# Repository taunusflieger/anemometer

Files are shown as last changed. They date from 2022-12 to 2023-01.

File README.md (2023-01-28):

# ESP32-S3 Espressif based 3D printed Anemometer


## About

This project will replace my broken anemometer (wind speed and wind direction sensor). The project is structured into two parts a.) a calibration solution which uses GPS to calibrate the sensor and b.) a production version which will be embedded into the 3D printed anemometer. The anemometer will be connect through Wifi with AWS to send (MQTT) measurements to the cloud where a web site is hosted. Given that the anemometer will be mounted on the roof of my house, it is important to be able to update the device without connecting a computer to it. Therefor OTA is implemented. The device can be updated by sending a MQTT message. The device downloads the requested firmware version from an AWS S3 bucket. All communication is secured using mutual TLS authentication. I'm also planning to power the device with a battery and a solar cell, that will require the implementation of a power management approach utilizing the low power modes of the used MCU.

## Scope

### Technical
- Reliable wifi connection, automatic reconnect (same for MQTT)
- MQTT transport of sensor data to AWS IoT core
- OTA update through HTTPS from AWS S3
- SNTP client to enable X.509 certificate validation and time stamping of measurement data
- NeoPixel for Wifi connection status indication
- IRQ routine to record anemometer rotation pulses (not decided if this will be ESP32-S3 and ULP)
- Local web server on the device for instant data
- All configuration data, specifically the AWS related configuration is stored in a separate partition in the NVM
- The application is written in Rust leveraging the ESP IDF framework
- The production and calibration use cases both use an ESP32-S3 MCU. The main reason not to use the ESP32-C3 is it's 4MB flash size limit which is too small to enable OTA functionality
- For production a [TinyS3 from UM](https://esp32s3.com/tinys3.html) is used as this is the smallest ESP32-S3 I've found

### Functional
- HTML page for providing current wind speed and direction
- Data feed to AWS where an external web interface is hosted
- The firmware supports multiple anemometer instances, as device specific information is stored outside of the fw image

### Functional for calibration use-case
- TFT to display current GPS and current wind speed
- Serial connection to a GPS receiver
- Recording of anemometer rotation speed and GPS data on a Micro SD card

## What is working
- Reliable wifi re-connect. When the wifi connection gets dropped, a re-connection process is started. When an IP address is received the HTTP Server is started again.
- HTTP Server
- OTA firmware download from AWS S3
- MQTT (sending data from the device, control the device OTA / reset) connection to AWS IoT core
- NVS for configuration storage
- Support for Adafruit Feather ESP32-S3 TFT display controller ST7789 (similar to ST7735). Implementation approach uses [mipidsi driver](https://github.com/almindor/mipidsi) 
- Output of GPS speed on TFT
- Logging of GPS NMEA sentences and anemometer rotation speed (rps) to SD card
- Rotation speed of anemometer processing and exposing through web interface (/windspeed)

## Todo List
- [x] Support for Adafruit [Ultimate GPS FeatherWing](https://learn.adafruit.com/adafruit-ultimate-gps-featherwing) to support the calibration process for the wind speed parameters. This is only required for the calibration use-case.
- [x] Support for Adafruit [Adalogger FeatherWing](https://learn.adafruit.com/adafruit-adalogger-featherwing) to log wind speed and GPS data. Interface through [Embedded SD/MMC](https://github.com/rust-embedded-community/embedded-sdmmc-rs). This is only required for the calibration use-case.
- [x] Evaluate pros and cons for using ESP32-S3 vs ESP32-C3 (power consumption, sleep, local web server, OTA needs to be considered)
- [x] ISR & event counting for windspeed sensor
- [x] Fully implement the feature approach to separate the calibration use case from production use case. The image for calibration is too large to allow OTA. Display, GPS and SD Card are not required for production. The solution has been split into a calibration and production solution.
- [x] Implement configuration settings for production in a seperate NVS partition
- [x] Add support for SNTP for production use case
- [ ] Modify existing AWS IoT interface to deal with wind only data (not the full weather dataset which is currently processed)
- [x] Implement MQTT for data ingress to AWS
- [ ] Implement sleep mode (which one ?)
- [ ] Calibration of the anemometer
- [ ] Implement new UI for the AWS lamda based weather station App

## Hardware Images

The board-setup used for the calibration use-case:

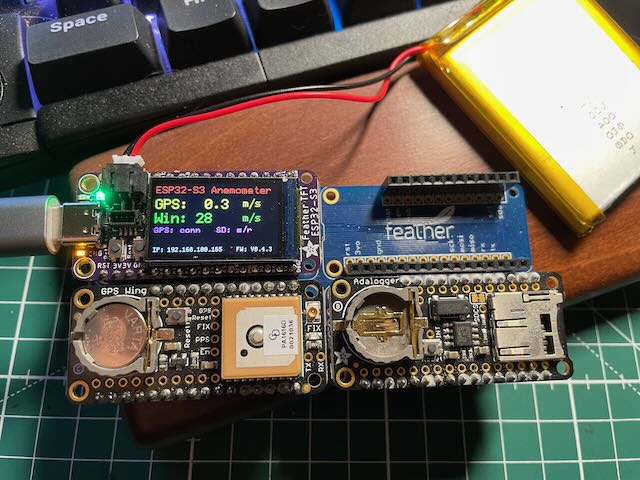
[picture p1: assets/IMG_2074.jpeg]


The 3D printed anemometer:

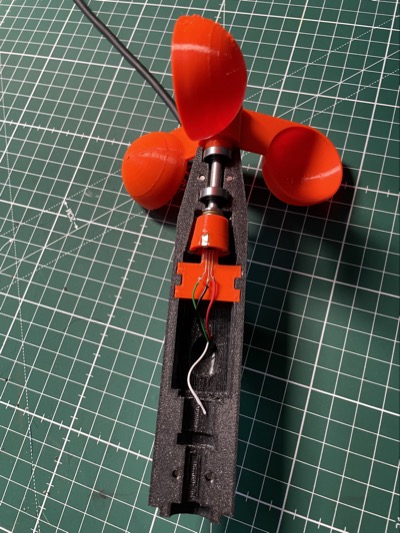
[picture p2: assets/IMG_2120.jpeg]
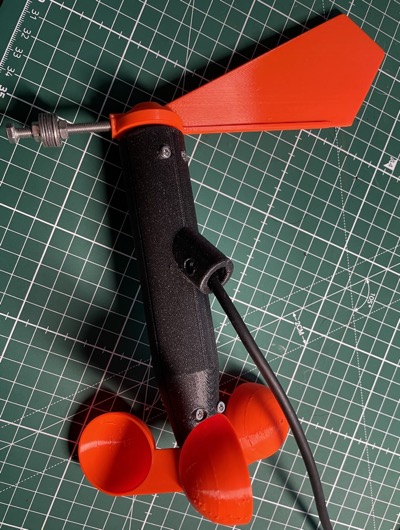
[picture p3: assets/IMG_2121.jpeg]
 

## Hardware BOM
- [SS41F](https://www.mouser.com/catalog/specsheets/hwsc-s-a0001295895-1.pdf). Hall- effect sensor to measure the rotation speed of the cups rotor

## License

Licensed under either of

- Apache License, Version 2.0 ([LICENSE-APACHE](LICENSE-APACHE) or
  http://www.apache.org/licenses/LICENSE-2.0)

- MIT license ([LICENSE-MIT](LICENSE-MIT) or http://opensource.org/licenses/MIT)

at your option.

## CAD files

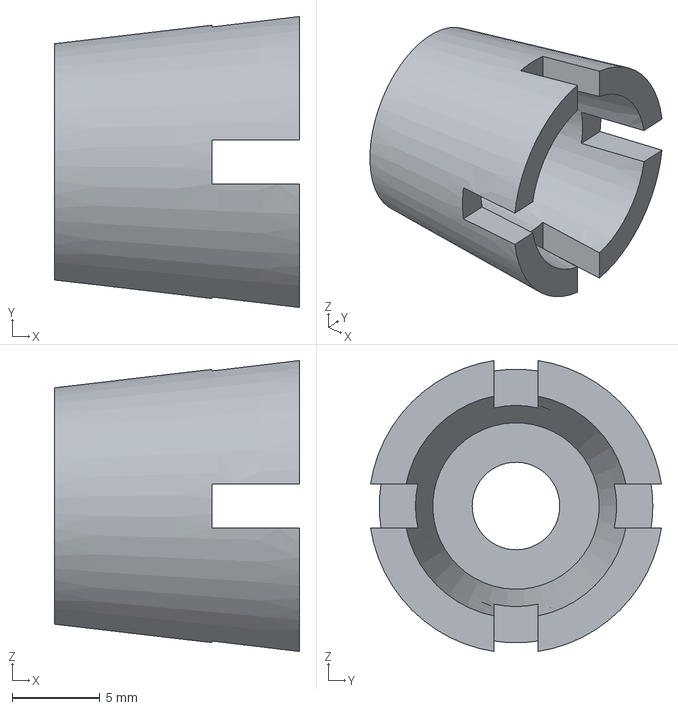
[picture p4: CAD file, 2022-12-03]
CAD/Magnetaufnahme.FCStd
14.0 x 16.6 x 16.6 mm

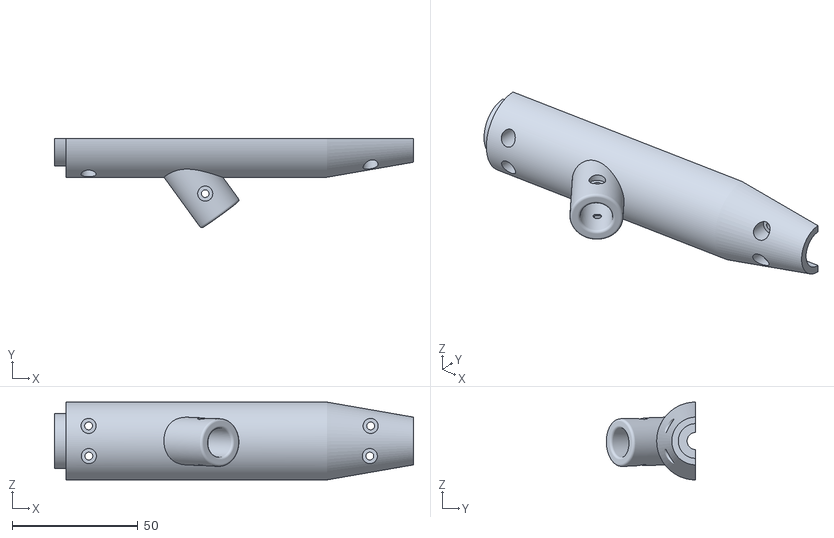
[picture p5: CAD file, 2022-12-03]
STL/housing_back.stl
142.9 x 35.5 x 31.0

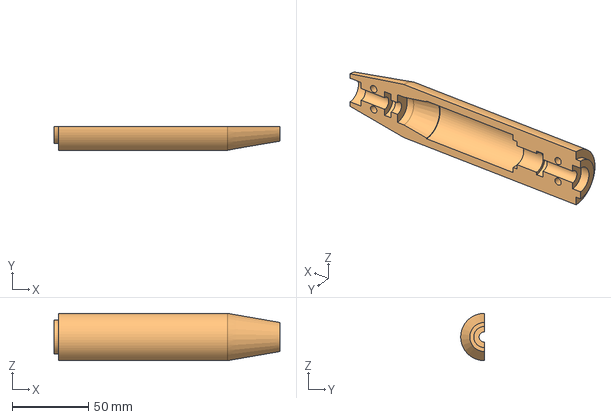
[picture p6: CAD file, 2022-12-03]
CAD/Housing_Bohrungen_front.FCStd
147.9 x 15.5 x 31.0 mm
Tube Corpus
Connect

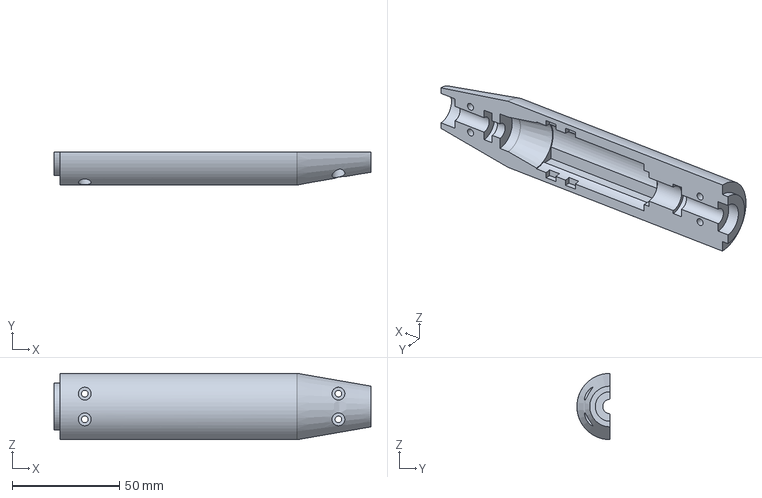
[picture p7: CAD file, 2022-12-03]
CAD/Housing_Bohrungen_back.FCStd
147.9 x 15.5 x 31.0 mm

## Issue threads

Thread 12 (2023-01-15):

minimal working OTA sample?

thomas725, 2023-01-15:
Hey there!

I'm currently trying to switch an ESP32 project of mine from Arduino to Rust because the Arduino software I've written get's sluggish over time and sometimes crashes, I suspect it has memory leaks.

Important feature I need is OTA, which seems is much more difficult with Rust than on Arduino, and your project is the first I've found that seems to have figured that one out. Sadly your project looks overwhelmingly big to my eyes, so I wanted to ask if you maybe could help me reach a minimal working OTA sample.

Thank you,
kind regards,
Thomas

taunusflieger, 2023-01-18:
Hi Thomas,the core OTA functionality is not much. Take a look at https://github.com/taunusflieger/anemometer/blob/master/anemometer-production/src/task/ota.rs
This where the fw download and the flashing happens.

taunusflieger, 2023-01-18:
.

Closed 2023-01-18.

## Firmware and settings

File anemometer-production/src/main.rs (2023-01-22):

/*
 * ESP32 Anemometer
 *
 * MIT license
 *
 * Copyright (c) 2021-2023 Michael Zill
 *
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
 * Apache license, Version 2.0
 *
 * Copyright (c) 2021-2023 Michael Zill
 *
 * Licensed under the Apache License, Version 2.0 (the "License");
 * you may not use this file except in compliance with the License.
 * You may obtain a copy of the License at
 *
 *     http://www.apache.org/licenses/LICENSE-2.0
 *
 * Unless required by applicable law or agreed to in writing, software
 * distributed under the License is distributed on an "AS IS" BASIS,
 * WITHOUT WARRANTIES OR CONDITIONS OF ANY KIND, either express or implied.
 * See the License for the specific language governing permissions and
 * limitations under the License.
 */
#![allow(incomplete_features)]
#![feature(generic_const_exprs)]
use crate::configuration::AwsIoTSettings;
use crate::global_settings::*;
use crate::services::*;
use crate::state::*;
use crate::task::{httpd, mqtt, ota::*, publisher};
use crate::utils::nvs_ext::*;
use crate::utils::{datetime, errors::*};
use channel_bridge::{asynch::pubsub, asynch::*};
use configuration::AwsIoTCertificates;
use edge_executor::*;
use edge_executor::{Local, Task};
use embedded_svc::utils::asyncify::Asyncify;
use embedded_svc::wifi::Wifi as WifiTrait;
use esp_idf_hal::reset::WakeupReason;
use esp_idf_hal::task::thread::ThreadSpawnConfiguration;
use esp_idf_hal::{cpu::*, task::executor::EspExecutor};
use esp_idf_svc::eventloop::EspSystemEventLoop;
use esp_idf_svc::netif::IpEvent;
use esp_idf_svc::nvs::EspDefaultNvsPartition;
use esp_idf_svc::nvs::*;
use esp_idf_svc::wifi::WifiEvent;
// If using the `binstart` feature of `esp-idf-sys`, always keep this module imported
use esp_idf_sys as _;
use esp_idf_sys::esp_ota_mark_app_valid_cancel_rollback;
use esp_idf_sys::{self as sys, esp, esp_wifi_set_ps, wifi_ps_type_t_WIFI_PS_MIN_MODEM};
use log::*;
use once_cell::sync::Lazy;
use std::sync::Mutex;

mod configuration;
mod data_processing;
mod global_settings;
mod mqtt_msg;
mod peripherals;
mod services;
mod state;
mod task;
mod utils;

//sys::esp_app_desc!();

static AWSCERTIFICATES: static_cell::StaticCell<AwsIoTCertificates> =
    static_cell::StaticCell::new();

pub static AWSCONFIG: Lazy<Mutex<AwsIoTSettings>> = Lazy::new(|| {
    Mutex::new(match AwsIoTSettings::new("conf") {
        Ok(settings) => settings,
        Err(err) => {
            error!("Failed to load AWS configuration: {err}");
            panic!();
        }
    })
});

fn main() -> core::result::Result<(), InitError> {
    esp_idf_hal::task::critical_section::link();
    esp_idf_svc::timer::embassy_time::driver::link();
    esp_idf_svc::timer::embassy_time::queue::link();

    esp_idf_svc::log::EspLogger::initialize_default();

    info!("ESP32-Anemometer");
    match core() {
        Core::Core0 => info!("running on core 0"),
        Core::Core1 => info!("running on core 1"),
    }
    let wakeup_reason = WakeupReason::get();
    info!("Wakeup reason: {:?}", wakeup_reason);

    let pm_config = esp_idf_sys::esp_pm_config_esp32s3_t {
        max_freq_mhz: MAX_CPU_FREQ,
        min_freq_mhz: MIN_CPU_FREQ,
        light_sleep_enable: LIGHT_SLEEP_MODE_ENABLED,
    };

    if let Err(err) =
        esp!(unsafe { esp_idf_sys::esp_pm_configure(&pm_config as *const _ as *const _) })
    {
        panic!("failed to set esp_pm_configure {err}");
    }

    let peripherals = peripherals::SystemPeripherals::take();
    let anemometer_peripherals = peripherals.pulse_counter;
    let nvs_default_partition = EspDefaultNvsPartition::take()?;
    let sysloop = EspSystemEventLoop::take()?;

    // Initialize data capture from anemometer
    let mut anemometer = anemometer::AnemometerDriver::new(anemometer_peripherals.pulse).unwrap();

    let _anemometer_timer = anemometer.set_measurement_timer().unwrap();

    let aws_iot_certificates: &'static AwsIoTCertificates =
        AWSCERTIFICATES.init(match AwsIoTCertificates::new("conf") {
            Ok(settings) => settings,
            Err(err) => {
                error!("Failed to load AWS configuration: {err}");
                panic!();
            }
        });

    let (wifi, wifi_notif) = wifi(
        peripherals.modem,
        sysloop.clone(),
        Some(nvs_default_partition),
    )?;

    esp!(unsafe { esp_wifi_set_ps(wifi_ps_type_t_WIFI_PS_MIN_MODEM) })?;

    let _sntp = utils::datetime::initialize();

    ThreadSpawnConfiguration {
        name: Some(b"high-prio-executor\0"),
        priority: TASK_HIGH_PRIORITY,
        ..Default::default()
    }
    .set()?;

    let _high_prio_execution = schedule::<8, _>(40000, move || {
        let executor = EspExecutor::new();
        let mut tasks = heapless::Vec::new();

        executor.spawn_local_collect(ota_task(aws_iot_certificates), &mut tasks)?;
        executor.spawn_local_collect(process_wifi_state_change(wifi, wifi_notif), &mut tasks)?;

        executor.spawn_local_collect(
            process_netif_state_change(netif_notifier(sysloop.clone()).unwrap()),
            &mut tasks,
        )?;

        Ok((executor, tasks))
    });

    ThreadSpawnConfiguration {
        name: Some(b"mid-prio-executor\0"),
        priority: TASK_MID_PRIORITY,
        ..Default::default()
    }
    .set()?;

    std::thread::sleep(core::time::Duration::from_millis(8000));

    let _mid_prio_execution = schedule::<8, _>(8000, move || {
        let executor = EspExecutor::new();
        let mut tasks = heapless::Vec::new();
        let (mqtt_client, mqtt_conn) = services::mqtt(aws_iot_certificates).unwrap();

        executor.spawn_local_collect(
            mqtt::send_task::<MQTT_MAX_TOPIC_LEN>(mqtt_client),
            &mut tasks,
        )?;
        executor.spawn_local_collect(mqtt::receive_task(mqtt_conn), &mut tasks)?;
        Ok((executor, tasks))
    });

    ThreadSpawnConfiguration {
        name: Some(b"low-prio-executor\0"),
        priority: TASK_LOW_PRIORITY,
        ..Default::default()
    }
    .set()?;

    let low_prio_execution = schedule::<8, _>(32000, move || {
        let executor = EspExecutor::new();
        let mut tasks = heapless::Vec::new();
        executor.spawn_local_collect(publisher::wind_speed_task(), &mut tasks)?;
        //executor.spawn_local_collect(httpd::http_server_task(), &mut tasks)?;

        Ok((executor, tasks))
    });

    if let Ok(datetime) = datetime::get_datetime() {
        let format =
            time::format_description::parse("[day].[month].[year] [hour]:[minute]:[second]")
                .expect("Invalid format.");

        let time = datetime.format(&format).expect("Could not format time.");
        info!("System start time: {time}");
    }

    low_prio_execution.join().unwrap();

    unreachable!();
}

pub fn schedule<'a, const C: usize, M>(
    stack_size: usize,
    spawner: impl FnOnce() -> core::result::Result<
            (Executor<'a, C, M, Local>, heapless::Vec<Task<()>, C>),
            SpawnError,
        > + Send
        + 'static,
) -> std::thread::JoinHandle<()>
where
    M: Monitor + Wait + Default,
{
    std::thread::Builder::new()
        .stack_size(stack_size)
        .spawn(move || {
            let (executor, tasks) = spawner().unwrap();

            executor.run_tasks(|| true, tasks);
        })
        .unwrap()
}

#[inline(always)]
pub fn netif_notifier(
    mut sysloop: EspSystemEventLoop,
) -> core::result::Result<impl Receiver<Data = IpEvent>, InitError> {
    Ok(pubsub::SvcReceiver::new(sysloop.as_async().subscribe()?))
}

pub async fn process_wifi_state_change(
    mut wifi: impl WifiTrait,
    mut state_changed_source: impl Receiver<Data = WifiEvent>,
) {
    loop {
        let event = state_changed_source.recv().await.unwrap();

        match event {
            WifiEvent::StaConnected => {}
            WifiEvent::StaDisconnected => {
                let mut publisher = NETWORK_EVENT_CHANNEL.publisher().unwrap();
                let _ = publisher.send(NetworkStateChange::WifiDisconnected).await;
                let _ = wifi.connect();
            }
            _ => {}
        }
    }
}

pub async fn process_netif_state_change(mut state_changed_source: impl Receiver<Data = IpEvent>) {
    loop {
        if let IpEvent::DhcpIpAssigned(assignment) = state_changed_source.recv().await.unwrap() {
            info!("IpEvent: DhcpIpAssigned: {:?}", assignment.ip_settings.ip);

            // if an IP address has been succesfully assiggned we consider
            // the application working, no rollback required.
            unsafe { esp_ota_mark_app_valid_cancel_rollback() };

            let mut publisher = NETWORK_EVENT_CHANNEL.publisher().unwrap();
            let _ = publisher
                .send(NetworkStateChange::IpAddressAssigned {
                    ip: assignment.ip_settings.ip,
                })
                .await;
        }
    }
}

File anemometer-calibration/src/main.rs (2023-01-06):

/*
 * ESP32 Anemometer
 *
 * MIT license
 *
 * Copyright (c) 2021-2023 Michael Zill
 *
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
 * Apache license, Version 2.0
 *
 * Copyright (c) 2021-2023 Michael Zill
 *
 * Licensed under the Apache License, Version 2.0 (the "License");
 * you may not use this file except in compliance with the License.
 * You may obtain a copy of the License at
 *
 *     http://www.apache.org/licenses/LICENSE-2.0
 *
 * Unless required by applicable law or agreed to in writing, software
 * distributed under the License is distributed on an "AS IS" BASIS,
 * WITHOUT WARRANTIES OR CONDITIONS OF ANY KIND, either express or implied.
 * See the License for the specific language governing permissions and
 * limitations under the License.
 */
use crate::anemometer::{AnemometerDriver, GLOBAL_ANEMOMETER_DATA};
use crate::gps_mtk3339::gps;
use crate::gps_mtk3339::gps::Mtk3339;
use crate::screen::anemometer_screen::LayoutManager;
use crate::web_server::url_handler;
use chrono::NaiveTime;
use core::mem;
use embedded_graphics::draw_target::DrawTarget;
use embedded_graphics::pixelcolor::Rgb565;
use embedded_graphics::prelude::*;
use embedded_svc::wifi::{self, AuthMethod, ClientConfiguration};
use esp_idf_hal::gpio;
use esp_idf_hal::gpio::*;
use esp_idf_svc::http::server::Configuration;
use esp_idf_svc::{
    eventloop::EspSystemEventLoop,
    netif::IpEvent,
    nvs::EspDefaultNvsPartition,
    wifi::{EspWifi, WifiEvent},
};
use esp_idf_sys as _;
use esp_idf_sys::{self as sys, esp, esp_wifi_set_ps, wifi_ps_type_t_WIFI_PS_NONE};
use log::info;
use smart_leds::{colors::*, RGB8};
use std::format;
use std::net::Ipv4Addr;
use std::rc::Rc;
use std::str;
use std::sync::mpsc;

mod anemometer;
mod display;
mod errors;
mod gps_mtk3339;
mod lazy_http_server;
mod neopixel;
mod peripherals;
mod screen;
mod sdmmc;
mod web_server;

sys::esp_app_desc!();

const FIRMWARE_VERSION: &str = env!("CARGO_PKG_VERSION");

const SSID: &str = env!("RUST_ESP32_ANEMOMETER_WIFI_SSID");
const PASS: &str = env!("RUST_ESP32_ANEMOMETER_WIFI_PASS");

enum WidgetName {
    GpsSpeed,
    WindSpeed,
}

struct DisplayCmd {
    widget: WidgetName,
    text: String,
}

#[allow(dead_code)]
enum SysLoopMsg {
    WifiDisconnect,
    IpAddressAsquired { ip: Ipv4Addr },

    NeopixelMsg { color: RGB8 },

    DisplayMsg { cmd: DisplayCmd },
    OtaUpdateStarted,

    NmeaData { data: String },
}

fn main() -> anyhow::Result<()> {
    esp_idf_svc::log::EspLogger::initialize_default();

    info!("Starting ...");
    let peripherals = peripherals::SystemPeripherals::take();

    let anemometer_peripherals = peripherals.pulse_counter;

    let mut status_led = neopixel::ws2812::NeoPixel::new(peripherals.neopixel)?;

    status_led.power_on(true);
    status_led.write(DARK_ORANGE)?;

    let display_peripherals = peripherals.display;
    let spi_bus_driver = peripherals.spi_bus.driver;
    let sdmmc_peripherals = peripherals.sdcard;

    let mut sd_card = sdmmc::SdCard::new(sdmmc_peripherals, Rc::clone(&spi_bus_driver))?;

    let mut display = display::display(display_peripherals, Rc::clone(&spi_bus_driver)).unwrap();

    let backlight = peripherals.display_backlight;

    display.clear(Rgb565::BLACK).unwrap();

    let layout_mgr = LayoutManager::new()?;

    layout_mgr.draw_initial_screen(&mut display).unwrap();
    layout_mgr
        .draw_sw_version(&mut display, format!("FW: V{}", FIRMWARE_VERSION).as_str())
        .unwrap();

    // we do it here to prevent garbage on the screen
    turn_backlight_on(backlight);

    // Initialize data capture from anemometer
    let mut anemometer = AnemometerDriver::new(anemometer_peripherals.pulse).unwrap();
    let _anemometer_timer = anemometer.set_measurement_timer().unwrap();

    let httpd = lazy_http_server::lazy_init_http_server::LazyInitHttpServer::new();
    let (tx, rx) = mpsc::channel::<SysLoopMsg>();

    info!("Wifi name {}", SSID);

    let nvs_default_partition = EspDefaultNvsPartition::take()?;
    let sysloop = EspSystemEventLoop::take()?;

    let mut wifi = EspWifi::new(
        peripherals.modem,
        sysloop.clone(),
        Some(nvs_default_partition),
    )?;

    wifi.set_configuration(&wifi::Configuration::Client(ClientConfiguration {
        ssid: SSID.into(),
        password: PASS.into(),
        auth_method: AuthMethod::WPA2WPA3Personal,
        ..Default::default()
    }))?;

    wifi.start()?;

    // disable power save
    esp!(unsafe { esp_wifi_set_ps(wifi_ps_type_t_WIFI_PS_NONE) })?;

    wifi.connect()?;
    info!("Connecting wifi ...");

    let tx0 = tx.clone();
    let tx1 = tx.clone();

    let tx2 = tx.clone();
    let tx3 = tx.clone();

    info!(" ************** Before UART backgound thread started");
    let _ = std::thread::Builder::new()
        .stack_size(16_000)
        .spawn(move || {
            info!("GPS Listening for messages");
            print_stack_remaining_size(16_000);
            let mut nmea = nmea::Nmea::default();
            print_stack_remaining_size(16_000);

            info!("Size of NMEA: {}", std::mem::size_of::<nmea::Nmea>());

            info!("Configure GPS receiver");
            let mut gps = Mtk3339::new(
                9600,
                peripherals.gps.uart1,
                peripherals.gps.tx,
                peripherals.gps.rx,
            )
            .unwrap();

            gps.send_command(gps::PMTK_SET_NMEA_OUTPUT_RMCGGA);
            gps.send_command(gps::PMTK_GPS_GLONASS);

            loop {
                let mut sentence = gps.read_line().unwrap();
                sentence = gps::Mtk3339::fix_rmc_sentence(sentence);

                info!("NMEA len:{} raw: {:?}", sentence.len(), sentence);

                if !sentence.is_empty() {
                    info!("================= NMEA parse");
                    let res = nmea.parse(sentence.as_str());
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

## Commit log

2022-11-05 OTA enabled, but flashing stops
    [partitions.csv]
2022-11-16 preliminary work for thread safety of neopixel
2022-11-18 Thread safe neopixel
2022-11-19 Switched from TinyS3 to Adafruit ESP32-S3
2022-12-03 GPS integrated
    [Housing_Bohrungen_back.FCStd, Housing_Bohrungen_front.FCStd, Magnetaufnahme.FCStd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]
2022-12-03 added CAD files for anemometer and driver for gps
    [Housing_Bohrungen_back.FCStd, Housing_Bohrungen_front.FCStd, Magnetaufnahme.FCStd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]
2022-12-05 fix for brockem RMC on MTK3339
    [gps_mtk3339.rs, main.rs]
2022-12-08 corrected GPS speed output to km/h
    [main.rs]
2022-12-09 refactored with SPIDriver peripheral not working
    [display.rs, main.rs, peripherals.rs]
2022-12-09 fixed lifetime issue with SpiDriver
    [peripherals.rs]
2022-12-18 update to README with current implementation
2022-12-21 enable esp32s3 and esp32c3 builds
2022-12-21 split features into production+calibration usecase
2022-12-22 switched to esp-idf-sys 0.32.1
2023-01-02 Reordered folder structure
    This is the first step in spliting the project in a calibration and into
    a production project. The production project follows an async approach
    utilizing Embassy while the calibration project remains using the IDF
    message loop directly.
    [partitions.csv]
2023-01-03 added nvs data
    [nvs.csv]
2023-01-04 AWS IoT config management added
    [nvs.csv, partitions.csv]
2023-01-06 anemometer sensor data processing added
2023-01-06 removed feature for calibration production
2023-01-11 production is now esp32s3
2023-01-16 restructuring and fix for not sending after time
    [main.rs]
2023-01-18 Fw download from AWS S3 bucket
2023-01-22 added app version to device shadow
2023-01-22 switched to official esp-idf-svc
2023-01-28 added initial HW BOM
